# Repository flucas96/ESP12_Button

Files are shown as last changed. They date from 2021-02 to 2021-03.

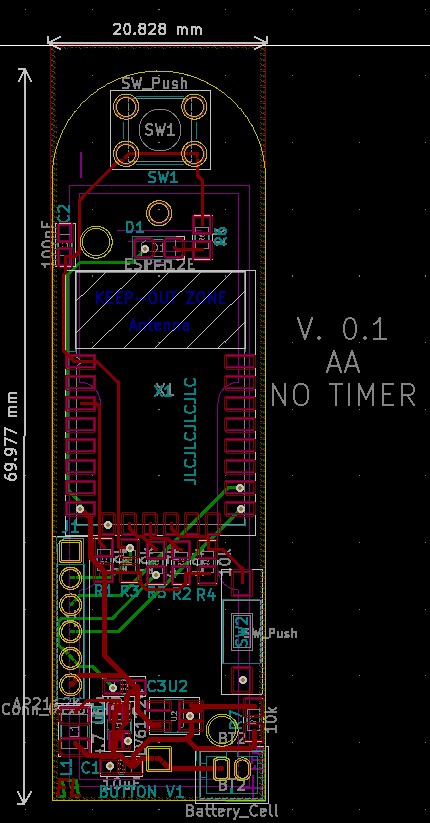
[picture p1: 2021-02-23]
button v2_1 - AA [TPL5110]/Button AA [Maße].jpg

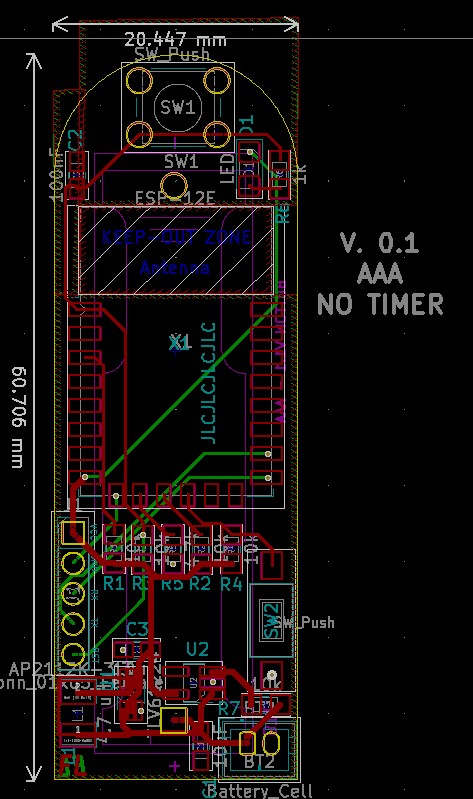
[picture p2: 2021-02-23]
button v2_1 - AAA [TPL5110]/Button AAA [Maße].jpg

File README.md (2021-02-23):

# ESP12_Button
:)

--> button - AA = Button mit einer AA-Batterie (ohne Timer)

--> button - AAA = Button mit einere AAA-Batterie (ohne Timer)

__________________________________________________________________________________________________________________________________

--> V.1.2.1 Coin Cell & V.1.2.2 Coin Cell sind gleich groß. (Unabhängig auch vom Timer der benutzt wird)

--> V.1.2.1 LIPO & V.1.2.2 LIPO sind gleich groß. (Unabhängig auch vom Timer der benutzt wird)

__________________________________________________________________________________________________________________________________

--> V1.2 Coin Cell&Lipo & V1.2 Coin Cell&Lipo[TPL5110] & V1.2 Coin Cell&Lipo[NO Timer] sind gleich groß wie das V1.2_Mosfet[Experiment]

__________________________________________________________________________________________________________________________________

Problem: Der Boost Converter, welcher für die Coin Cell benötigt wird, schaltet durch wenn EN LOW ist anstatt den Stromfluss zu trennen. 
(Besteht nur bei den Versionen mit dem TPL5111) (Die Versionen deren Ordern mit "OLD" endet sind wahrscheinlich nicht voll funktionsfähig. 
Der ESP12 weiterhin Strom bekommen auch wenn der Timer LOW ist. Dadurch geht der Vorteil, der durch den Timer erreicht werden soll verloren 
und die Versionen sollten gleich gut performen (wenn nicht sogar schlechter) als die ohne Timer. Da, der Boost Converter für dieses Verhalten
verantworlich ist, tretten die Probleme nur bei den Versionen, welche die Nutzung einer Coin Cell voraussehen, auf.

Lösungen: Anderer Boost Converter ()/ Transistor der den ESP zusätzlich an/ausschaltet (V1.2.3) / TPL5110 verwenden (v1.2 / v1.2.3)

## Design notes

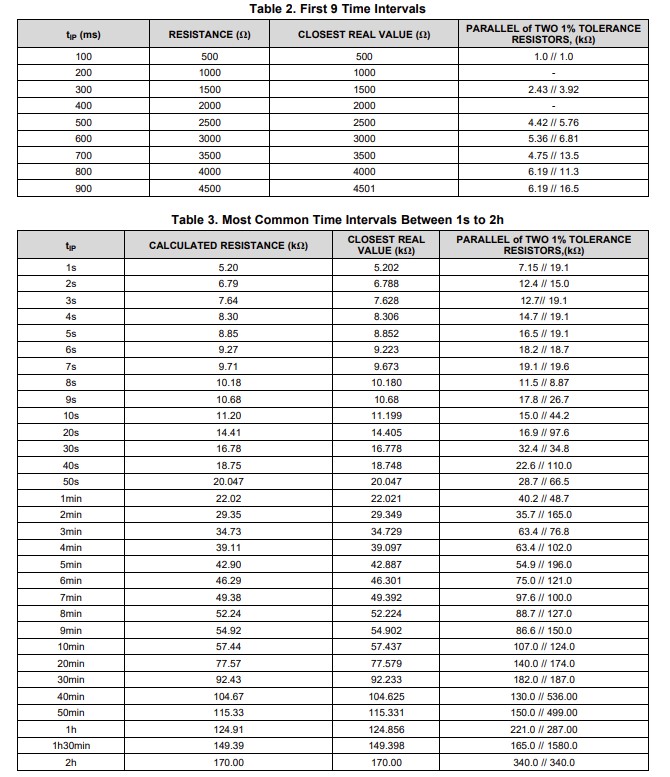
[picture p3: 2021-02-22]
button_v1.2.2_lipo[NO TIMER] -- corrected/resistor values.jpg

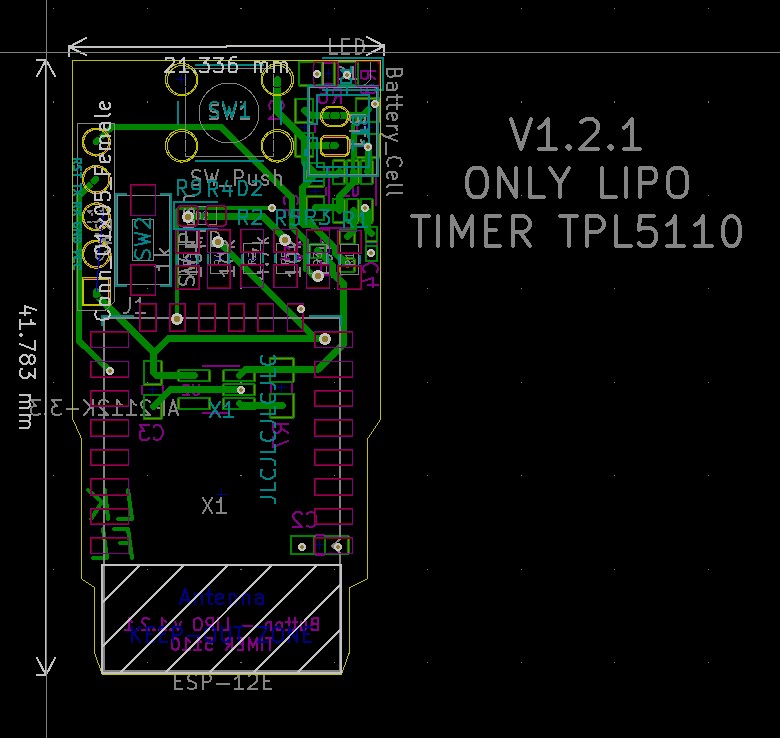
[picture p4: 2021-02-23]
button_timer_v1.2.1_lipo[TPL5110] - corrected/V1.2.1 LIPO ONLY[Maße].jpg

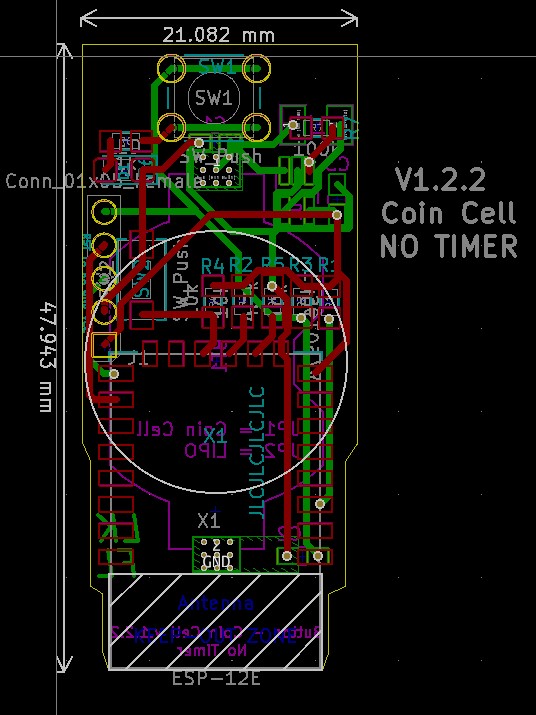
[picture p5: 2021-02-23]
button_v1.2.2_Coin_Cell[NO TIMER] -- corrected/V1.2.2 Coin Cell No Timer[Maße].jpg

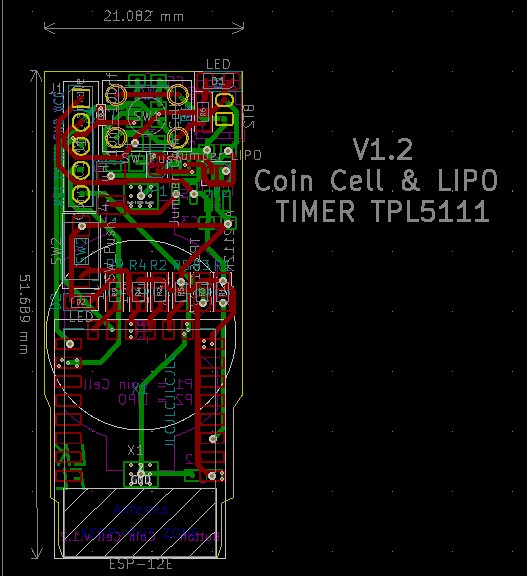
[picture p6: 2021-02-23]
button_timer v1.2.4_[Coin_Cell&LIPO][NO TIMER] - corrected/Coin Cell & Lipo V1.2 [Maße].jpg

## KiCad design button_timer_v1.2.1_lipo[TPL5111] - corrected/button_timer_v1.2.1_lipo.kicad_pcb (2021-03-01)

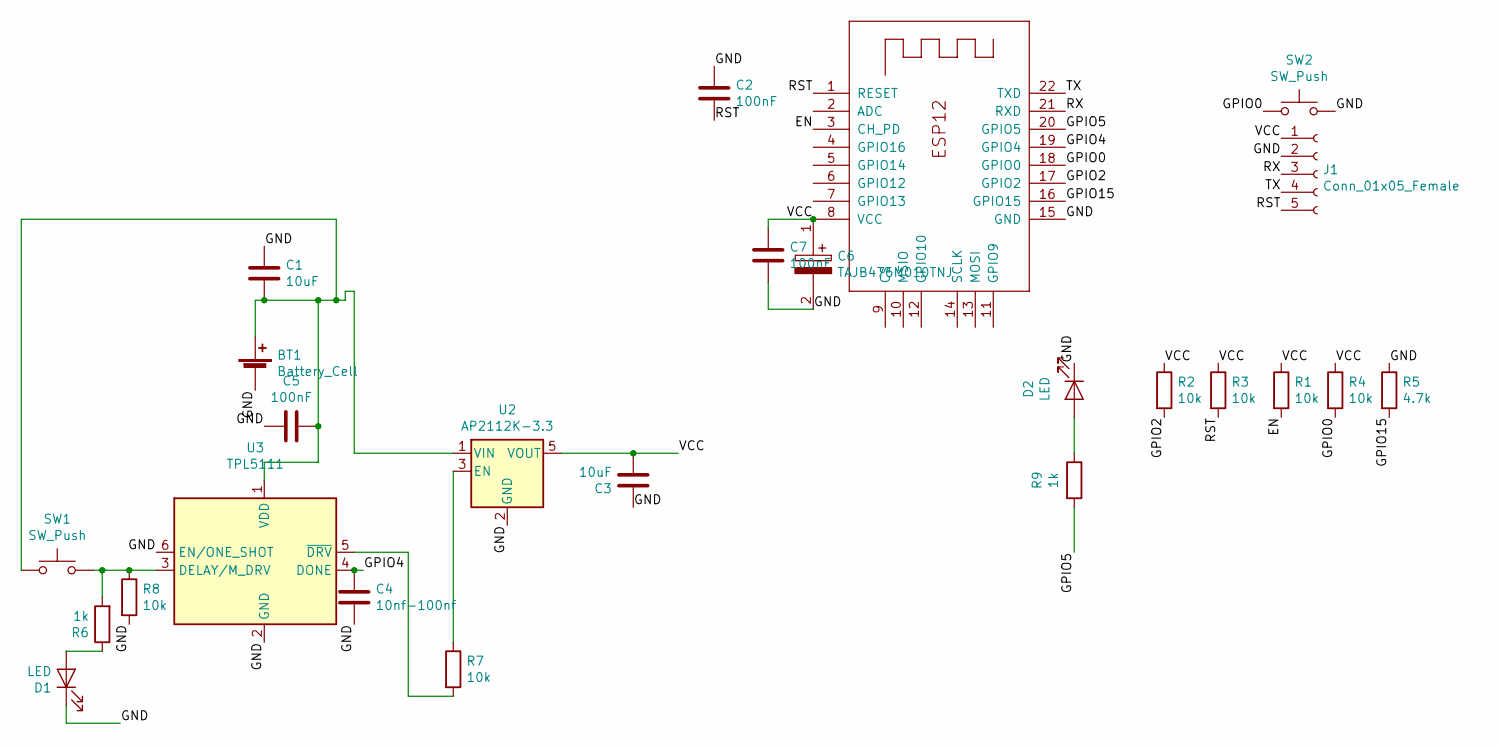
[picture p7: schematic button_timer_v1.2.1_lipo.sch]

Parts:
BT1: Battery_Cell; JST_PH_B2B-PH-K_1x02_P2.00mm_Vertical
C1, C3: 10uF; C_0805_2012handsodermod
C2: 100nF; C_0805_2012handsodermod
C4: 10nf-100nf; C_0402_1005Metric_Pad0.74x0.62mm_HandSolder
C5, C7: 100nF; C_0402_1005Metric_Pad0.74x0.62mm_HandSoldermod
C6: TAJB476M010TNJ; CAPPM3528X210N; Manufacturer_Part_Number TAJB476M010TNJ; Mouser Part Number 581-TAJB476M010TNJ
D1: LED; LED_0805_2012Metric_Castellated_mod
D2: LED; LED_1206_3216Metric_Castellated
J1: Conn_01x05_Female; PinSocket_1x05_P2.54mm_Vertical
R1, R2, R3, R4, R7, R8: 10k; R_0805_2012handsoldermod
R5: 4.7k; R_0805_2012handsoldermod
R6, R9: 1k; R_0805_2012handsoldermod
SW1: SW_Push; SW_PUSH_6mm_H8mm
SW2: SW_Push; SW_SPST_B3U-1000P
U2: AP2112K-3.3; SOT-23-5_HandSolderingmod
U3: TPL5111; SOT-23-6handsoldering
X1: ESP-12E; ESP-12Elesssilk

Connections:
/EN: R1.2, X1.3 (CH_PD)
/GND: BT1.2 (-), C1.1, C2.1, C3.1, C4.2, C5.2, C6.2, C7.2, D1.1 (K), D2.1 (K), J1.2, R5.1, R8.2, SW2.2, U2.2 (GND), U3.2 (GND), U3.6 (EN/ONE_SHOT), X1.15 (GND)
/GPIO0: R4.2, SW2.1, X1.18 (GPIO0)
/GPIO2: R2.2, X1.17 (GPIO2)
/GPIO4: C4.1, U3.4 (DONE), X1.19 (GPIO4)
/GPIO5: R9.2, X1.20 (GPIO5)
/GPIO15: R5.2, X1.16 (GPIO15)
/RST: C2.2, J1.5, R3.2, X1.1 (RESET)
/RX: J1.3, X1.21 (RXD)
/TX: J1.4, X1.22 (TXD)
/VCC: C3.2, C6.1, C7.1, J1.1, R1.1, R2.1, R3.1, R4.1, U2.5 (VOUT), X1.8 (VCC)
unnamed: BT1.1 (+), C1.2, C5.1, SW1.1, U2.1 (VIN), U3.1 (VDD)
unnamed: D1.2 (A), R6.1
unnamed: D2.2 (A), R9.1
unnamed: R6.2, R8.1, SW1.2, U3.3 (DELAY/M_DRV)
unnamed: R7.1, U2.3 (EN)
unnamed: R7.2, U3.5 (~DRV)

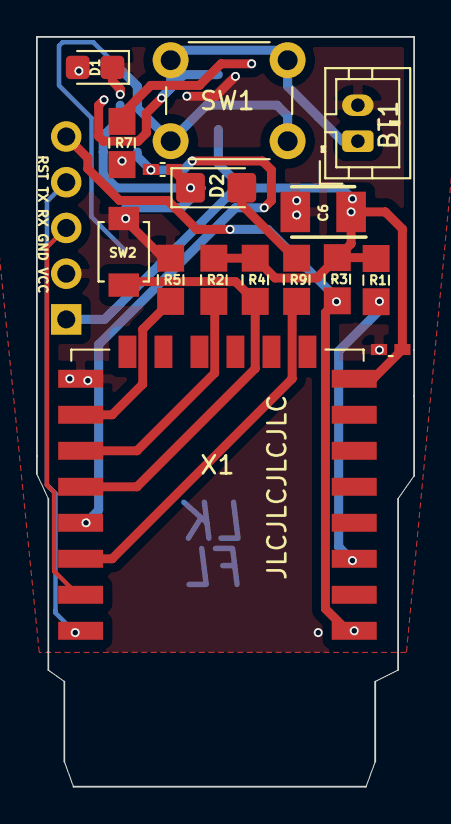
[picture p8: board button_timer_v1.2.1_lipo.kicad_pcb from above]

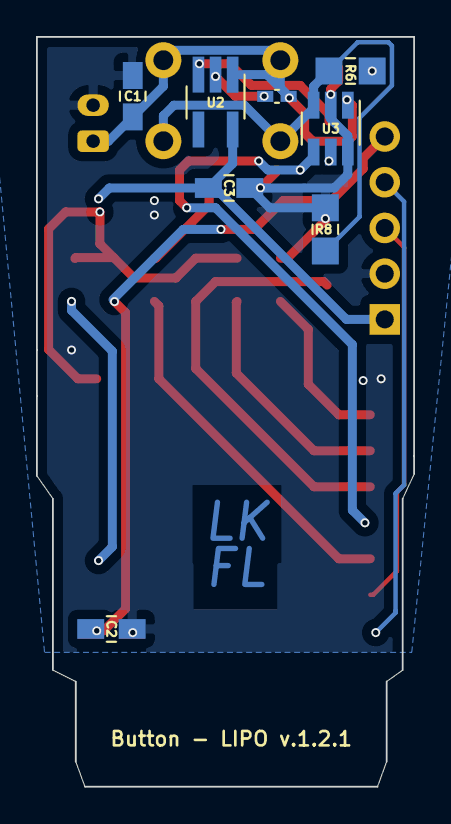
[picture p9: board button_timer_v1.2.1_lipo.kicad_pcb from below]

Board: 2 copper layers, 21.0 x 41.7 mm, 25 parts (8 on the bottom side), 17 nets.

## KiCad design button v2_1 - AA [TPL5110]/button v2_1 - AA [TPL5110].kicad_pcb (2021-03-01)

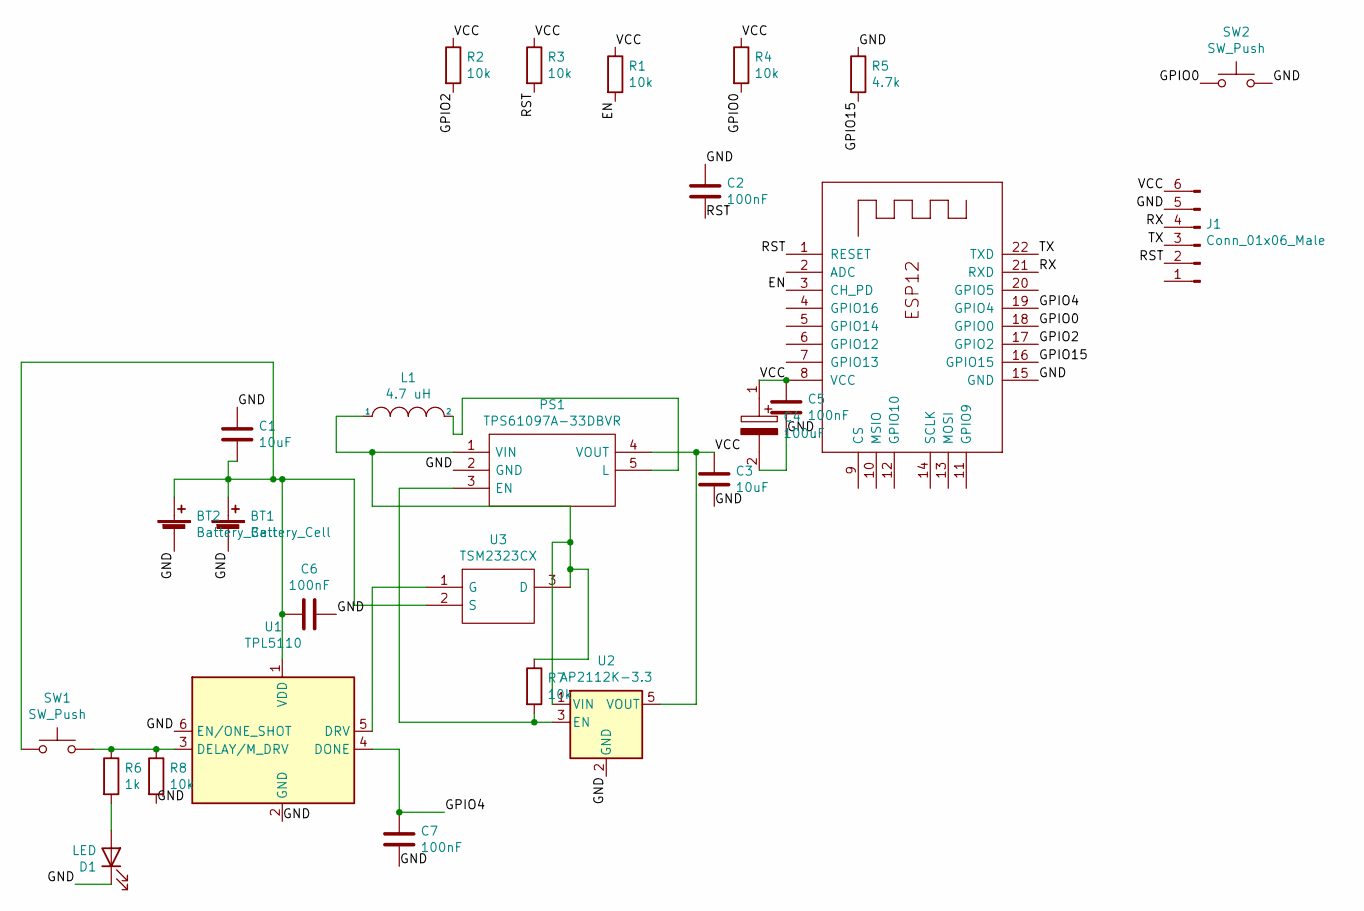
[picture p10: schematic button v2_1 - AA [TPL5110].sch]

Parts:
BT1: Battery_Cell; BatteryHolder_Keystone_2460_1xAA
BT2: Battery_Cell; JST_PH_B2B-PH-K_1x02_P2.00mm_Vertical
C1, C3: 10uF; C_0805_2012handsodermod
C2, C5, C6, C7: 100nF; C_0402_1005Metric_Pad0.74x0.62mm_HandSoldermod
C4: 100uF; CAPPM3528X210N; Manufacturer_Part_Number TAJB476M010TNJ; Mouser Part Number 581-TAJB476M010TNJ
D1: LED; LED_1206_3216Metric_Castellated
J1: Conn_01x06_Male; PinHeader_1x06_P2.54mm_Vertical
L1: 4.7 uH; SMD-1210_Pol_inductor
PS1: TPS61097A-33DBVR; SOT-23-5_HandSolderingmod; Manufacturer_Part_Number TPS61097A-33DBVR; Mouser Part Number 595-TPS61097A-33DBVR
R1, R2, R3, R4, R7: 10k; R_0805_2012handsoldermod
R5: 4.7k; R_0805_2012handsoldermod
R6: 1k; C_0805_2012handsodermodmod
R8: 10k; R_0603_1608Metric_Pad0.98x0.95mm_HandSolder_mod
SW1: SW_Push; SW_PUSH_6mm
SW2: SW_Push; button_smd_hmsensor
U1: TPL5110; SOT-23-6handsoldering
U2: AP2112K-3.3; SOT-23-5_HandSolderingmod
U3: TSM2323CX; SOT-23; Manufacturer_Part_Number TSM2323CX; Mouser Part Number 821-TSM2323CX
X1: ESP-12E; ESP-12Elesssilk

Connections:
/EN: R1.2, X1.3 (CH_PD)
/GND: BT1.2 (-), BT2.2 (-), C1.1, C2.1, C3.2, C4.2, C5.2, C6.1, C7.2, D1.1 (K), J1.5, PS1.2 (GND), R5.1, R8.2, SW2.2, U1.2 (GND), U1.6 (EN/ONE_SHOT), U2.2 (GND), X1.15 (GND)
/GPIO0: R4.2, SW2.1, X1.18 (GPIO0)
/GPIO2: R2.2, X1.17 (GPIO2)
/GPIO4: C7.1, U1.4 (DONE), X1.19 (GPIO4)
/GPIO15: R5.2, X1.16 (GPIO15)
/RST: C2.2, J1.2, R3.2, X1.1 (RESET)
/RX: J1.4, X1.21 (RXD)
/TX: J1.3, X1.22 (TXD)
/VCC: C3.1, C4.1, C5.1, J1.6, PS1.4 (VOUT), R1.1, R2.1, R3.1, R4.1, U2.5 (VOUT), X1.8 (VCC)
unnamed: BT1.1 (+), BT2.1 (+), C1.2, C6.2, SW1.1, U1.1 (VDD), U3.2 (S)
unnamed: D1.2 (A), R6.2
unnamed: L1.1, PS1.1 (VIN), R7.1, U2.1 (VIN), U3.3 (D)
unnamed: L1.2, PS1.5 (L)
unnamed: PS1.3 (EN), R7.2, U2.3 (EN)
unnamed: R6.1, R8.1, SW1.2, U1.3 (DELAY/M_DRV)
unnamed: U1.5 (DRV), U3.1 (G)

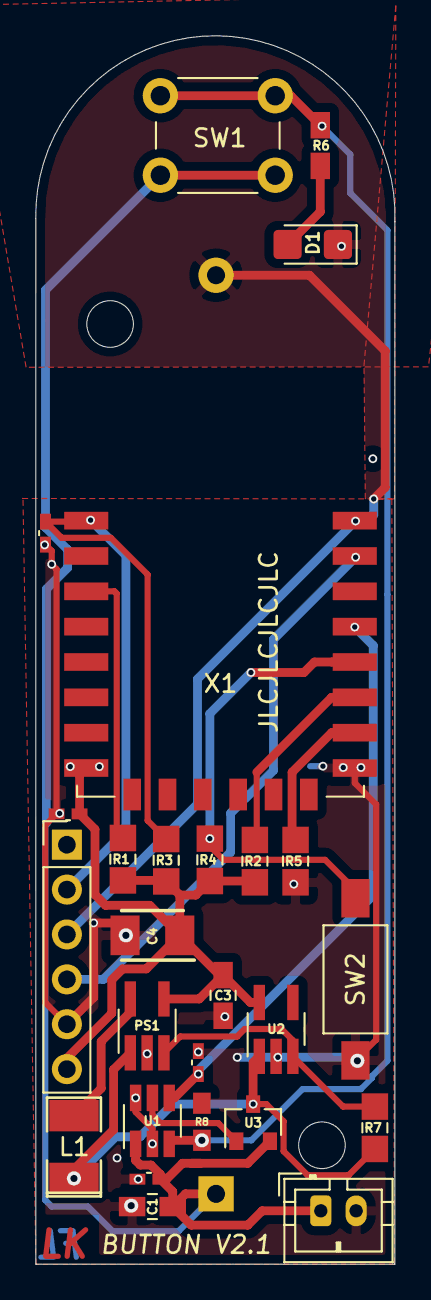
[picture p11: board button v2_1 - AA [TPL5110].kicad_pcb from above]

Board: 2 copper layers, 20.3 x 69.5 mm, 27 parts (1 on the bottom side), 17 nets.

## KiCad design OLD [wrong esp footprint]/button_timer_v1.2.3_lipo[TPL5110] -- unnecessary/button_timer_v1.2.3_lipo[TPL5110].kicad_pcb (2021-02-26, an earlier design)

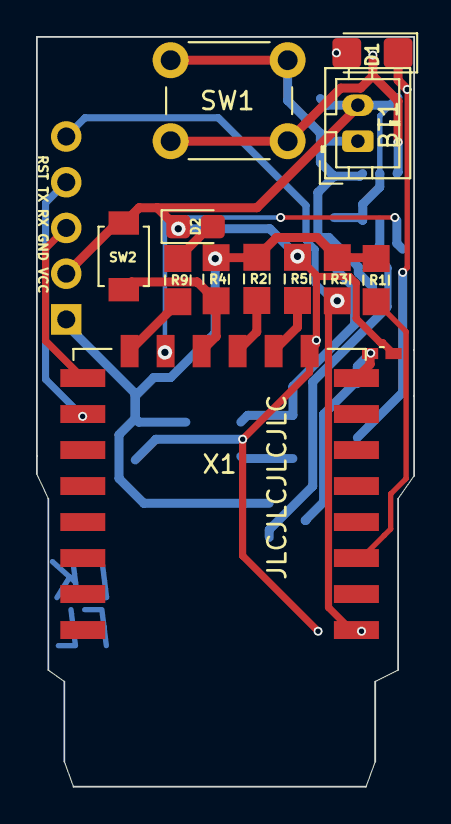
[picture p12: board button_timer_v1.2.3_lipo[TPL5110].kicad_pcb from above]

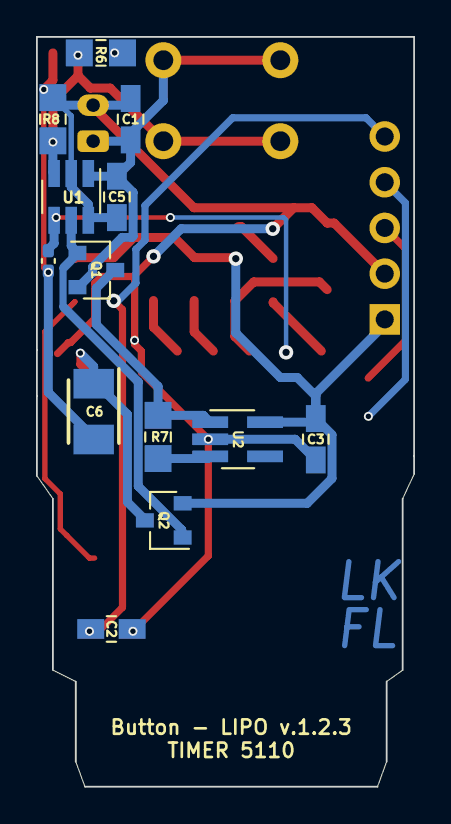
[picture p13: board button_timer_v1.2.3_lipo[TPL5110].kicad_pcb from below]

Board: 2 copper layers, 21.0 x 41.7 mm, 27 parts (13 on the bottom side), 19 nets.

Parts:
BT1: Battery_Cell; JST_PH_B2B-PH-K_1x02_P2.00mm_Vertical
C1, C3: 10uF; C_0805_2012handsodermod
C2, C5: 100nF; C_0805_2012handsodermod
C4: 10nf-100nf; C_0402_1005Metric_Pad0.74x0.62mm_HandSolder
C6: TAJB476M010TNJ; CAPPM3528X210N
C7: 100nF; C_0402_1005Metric_Pad0.74x0.62mm_HandSoldermod
D1: LED; LED_1206_3216Metric_Castellated
D2: LED; LED_0805_2012Metric_Castellated_mod
J1: Conn_01x05_Female; PinSocket_1x05_P2.54mm_Vertical_mod
Q1, Q2: TSM2301ACX; SOT-23
R1, R2, R3, R4, R8: 10k; R_0805_2012handsoldermod
R5: 4.7k; R_0805_2012handsoldermod
R6, R9: 1k; R_0805_2012handsoldermod
R7: 100k; R_0805_2012handsoldermod
SW1: SW_Push; SW_PUSH_6mm_H8mm_mod
SW2: SW_Push; SW_SPST_B3U-1000P_mod
U1: TPL5110; SOT-23-6handsoldering
U2: AP2112K-3.3; SOT-23-5_HandSolderingmod
X1: ESP-12E; ESP-12Elesssilk

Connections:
/EN: R1.2, X1.3
/GND: BT1.2, C1.1, C2.1, C3.1, C4.2, C5.1, C6.2, C7.2, D1.1, D2.1, J1.2, R5.1, R8.2, SW2.2, U1.2, U1.6, U2.2, X1.9
/GPIO0: R4.2, SW2.1, X1.12
/GPIO2: R2.2, X1.11
/GPIO4: C4.1, U1.4, X1.13
/GPIO5: R9.2, X1.14
/GPIO15: R5.2, X1.10
/RST: C2.2, J1.5, R3.2, X1.1
/RX: J1.3, X1.15
/TX: J1.4, X1.16
/VCC: C3.2, J1.1, Q2.2, R1.1, R2.1, R3.1, R4.1, U2.5
/VCC_ESP: C6.1, C7.1, Q2.3, X1.8
unnamed: BT1.1, C1.2, C5.2, Q1.2, SW1.1, U1.1
unnamed: D1.2, R6.1
unnamed: D2.2, R9.1
unnamed: Q1.1, Q2.1, U1.5
unnamed: Q1.3, R7.1, U2.1
unnamed: R6.2, R8.1, SW1.2, U1.3
unnamed: R7.2, U2.3

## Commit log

2021-02-22 clean up
    [button - AAA-B_Cu.gbr, button - AAA-B_Mask.gbr, button - AAA-B_Paste.gbr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]
2021-02-22 23.02 00:38
    [button timer v1.2.1_Coin_Cell.kicad_pcb, button_timer_v1.2.1_lipo.kicad_pcb, button_v1.2.2_Coin_Cell.kicad_pcb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]
2021-02-22 23.02 00:40
    [button timer v1.2.kicad_pcb, button_timer_v1.2_mosfet.kicad_pcb]
2021-02-23 23.02 13:31
    [button timer v1.2.1_Coin_Cell.kicad_pcb, button timer v1.2.1_Coin_Cell.sch, button timer v1.2.kicad_pcb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]
2021-02-23 TPL 5110 version
    [button timer v1.2.1_Coin_Cell.kicad_pcb, button timer v1.2.1_Coin_Cell.sch, button_timer_v1.2.1_lipo.kicad_pcb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]
2021-02-23 Bilder von den Maßen hinzugefügt
    [button - AAA.kicad_pcb, button timer v1.2.1_Coin_Cell.kicad_pcb, button timer v1.2.kicad_pcb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]
2021-02-23 :rocket: :full_moon_with_face:
    [button timer v1.2.1_Coin_Cell.kicad_pcb, button timer v1.2.1_Coin_Cell.sch, button timer v1.2_[Coin_Cell&LIPO][TPL5110].kicad_pcb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]
2021-02-23 3D Models etwas verbessert
    [button timer v1.2.1_Coin_Cell.kicad_pcb, button timer v1.2.1_Coin_Cell.sch, button timer v1.2.kicad_pcb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]
2021-02-23 :rocket: :new_moon:
    [button timer v1.2.1_Coin_Cell.kicad_pcb, button timer v1.2.1_Coin_Cell.sch, button_v1.2.2_lipo.kicad_pcb]
2021-02-23 TO THE MOON
    [button timer v1.2.1_Coin_Cell.kicad_pcb, button timer v1.2.1_Coin_Cell.sch, button timer v1.2.3_Coin_Cell[TPL5111].kicad_pcb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]
2021-02-23 :rocket: :moon: :100:
    [button timer v1.2.3_Coin_Cell[TPL5111].sch, button timer v1.2.3_[Coin_Cell&LIPO][TPL5111].kicad_pcb, button_v1.2.2_lipo.kicad_pcb]
2021-02-23 TO JUPITER :rocket:
    [button timer v1.2.1_Coin_Cell.kicad_pcb, button timer v1.2.3_Coin_Cell[TPL5111].kicad_pcb, button timer v1.2.3_Coin_Cell[TPL5111].sch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]
2021-02-23 Silkscreen Update
    [button timer v1.2.1_Coin_Cell.kicad_pcb, button timer v1.2.3_Coin_Cell[TPL5111].kicad_pcb, button timer v1.2.3_[Coin_Cell&LIPO][TPL5111].kicad_pcb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]
2021-02-24 cap between esp vcc and ground added
    [button timer v1.2.3_Coin_Cell[TPL5111].kicad_pcb, button timer v1.2.3_Coin_Cell[TPL5111].sch, button timer v1.2.3_[Coin_Cell&LIPO][TPL5111].kicad_pcb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]
2021-02-24 cap added between vcc and gnd of the esp
    [button timer v1.2.1_Coin_Cell.kicad_pcb, button timer v1.2.1_Coin_Cell.sch, button timer v1.2.kicad_pcb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]
2021-02-24 Added 100nF decoupling capacitors between VCC and Ground of the ESP
    [button timer v1.2.1_Coin_Cell.kicad_pcb, button timer v1.2.1_Coin_Cell.sch, button timer v1.2.3_Coin_Cell[TPL5111].kicad_pcb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]
2021-02-25 turned around some of the LIPO connectors
    [button timer v1.2.1_Coin_Cell.kicad_pcb, button timer v1.2.1_Coin_Cell.sch, button timer v1.2.3_Coin_Cell[TPL5111].kicad_pcb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]
2021-02-26 added BOMs
    [button - AAA.kicad_pcb, button - AAA.sch, button timer v1.2.1_Coin_Cell.kicad_pcb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]
2021-02-28 All Footprints corrected
    [button_timer_v1.2.1_lipo.kicad_pcb, button_timer_v1.2.1_lipo.sch, button_timer_v1.2.1_lipo[TPL5110].kicad_pcb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]
2021-03-01 added timer version for AA and AAA
    [button v2_1 - AA [TPL5110].kicad_pcb, button v2_1 - AA [TPL5110].sch, button v2_1 - AAA [TPL5110].kicad_pcb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]
